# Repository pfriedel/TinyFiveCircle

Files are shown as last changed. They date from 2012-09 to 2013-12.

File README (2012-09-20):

Requirements:

1) 5 RGB LEDs - I'm using common anode, but it'll work with common cathode.
   Just differently.  You'll have to map out the pins and colors differently.

2) ATtiny85

3) PCB from OSHpark.  I'm working on a kit.

BOM: (prices are volatile)

1x MCU: http://www.dipmicro.com/store/ATTINY85-20PU ($1.56)
4x 10mm RGB Common Anode LEDs: http://www.dipmicro.com/store/LED10AD ($2)
1x 3xAA Battery holder: http://www.dipmicro.com/store/BH2465 ($3.21)
4x resistors - mine are 1ohm! But 47 is probably more reasonable

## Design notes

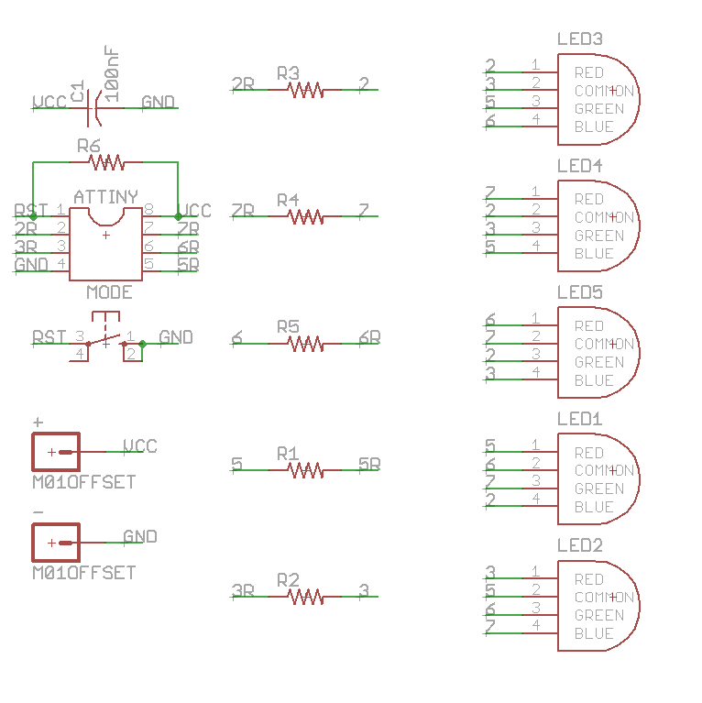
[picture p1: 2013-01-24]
Boards/Tiny RGB Schematic.png

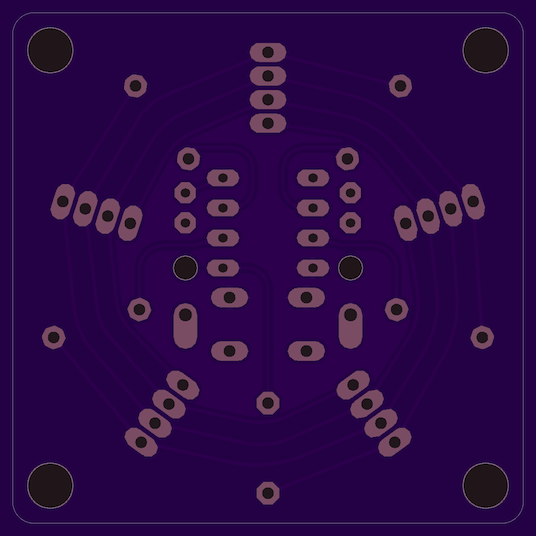
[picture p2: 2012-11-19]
Boards/board_bottom.png

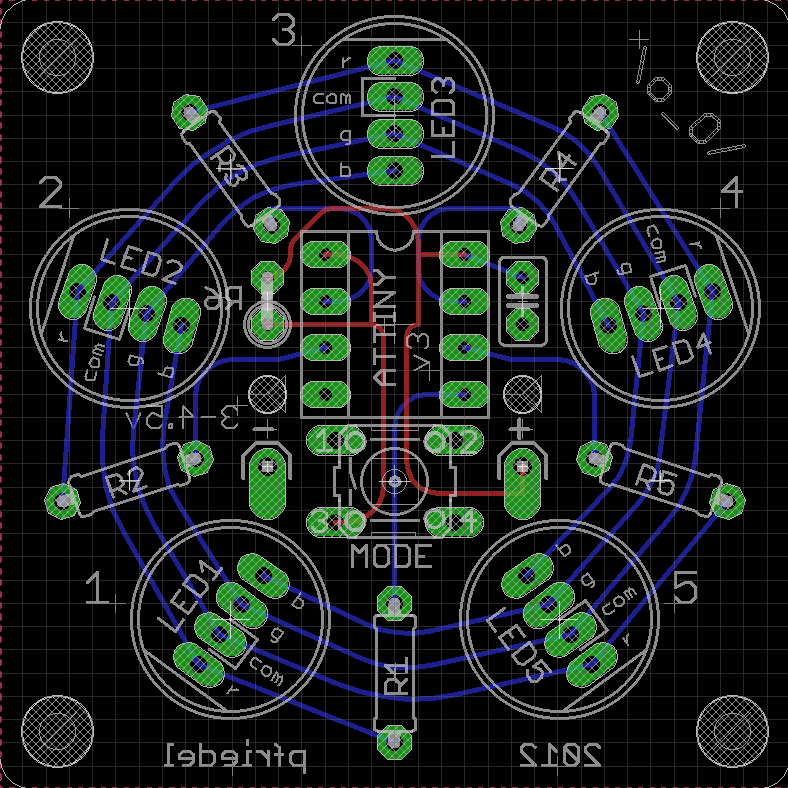
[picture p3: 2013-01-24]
Boards/Tiny RGB Board.png

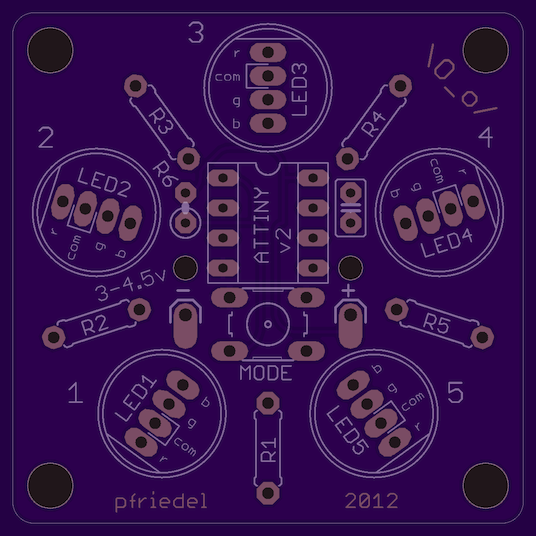
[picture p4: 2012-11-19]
Boards/board_top.png

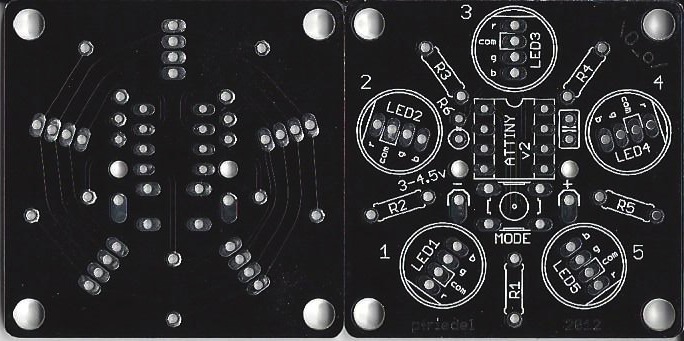
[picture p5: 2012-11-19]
Boards/iTead Boards.jpg

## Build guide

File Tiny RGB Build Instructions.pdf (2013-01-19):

# Tiny RGB Build Instructions

## PARTS LIST:

Quantity | Name | Location | Description
1 | Circuit Board | -
5 | 10mm Common Anode RGB LEDs | LED1-LED5
5 | 68 Ω resistors | R1-R5 | blue - gray - black - silver - brown
1 | 10k Ω resistor | R6 | brown - black - black - red - brown
1 | 100 nF capacitor | - | Labeled “104”
1 | 8 pin socket | ATTINY
1 | ATtiny85 | ATTINY | ATTINY85-20PU
1 | Tact Switch | MODE | 6 x 6 x 15 mm
1 | 3 x AA Battery Box

## BUILD INSTRUCTIONS:

Please familiarize yourself with all of the instructions before you begin as there are some helpful hints scattered throughout the project that help with later steps.

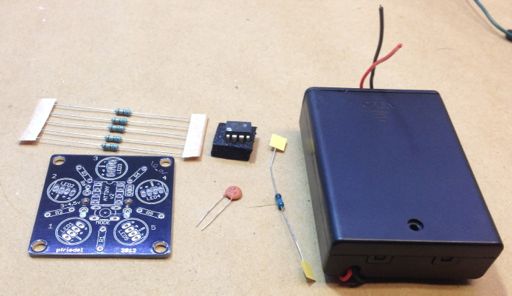
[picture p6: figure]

1. The contents of the kit - the circuit board, five 68 Ω resistors on a strip, a solitary 10k Ω resistor, the 100 nF capacitor, the microcontroller in a piece of foam and the battery box. The LEDs, socket, and tact switch are all inside the battery compartment. If you can’t find a part, open up the battery box and inspect it carefully - I may have changed how I pack everything, but it will all be in the static bag.

There might be slight cosmetic differences to the board between production runs, but the part locations should stay consistent. The general philosophy of what order the parts are installed generally goes from shortest to tallest. Since the resistors are the shorted items in the kit, let’s start with them!

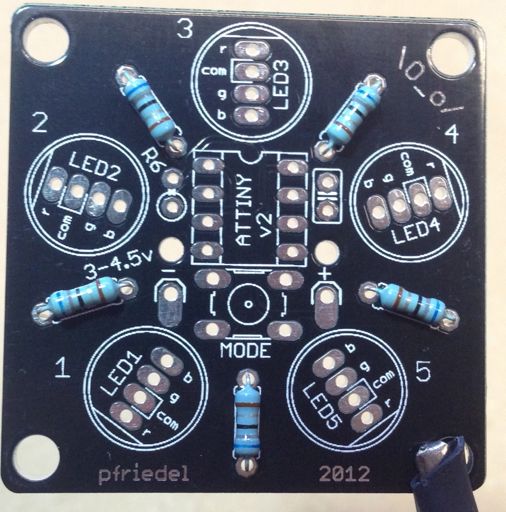
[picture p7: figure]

2. First insert all five 68 Ω resistors in positions R1 through R5 as shown. Flip the circuit board over and solder them and clip the excess leads once they’re soldered. Resistors don’t have any polarity, so you can insert them in either direction. You can solder them one by one if you’re more comfortable soldering them that way.

The 68 Ω resistor looks like this:

These resistors act as current limiters for the LEDs. If you swap them for ones with smaller values, the first thing that tends to happen is the microcontroller goes into a constant state of reset and nothing happens or the system flickers and restarts continually. If you let it happen for long enough, you could also burn out the microcontroller or possibly damage an LED. This is voltage sensitive: If you intend on using this from a 3v source, you can get away with smaller resistors - 27 Ω is comfortable for 3v for example. 68 Ω is plenty for 4.5v and what is included in the kit.

2012-nov-25 / 1

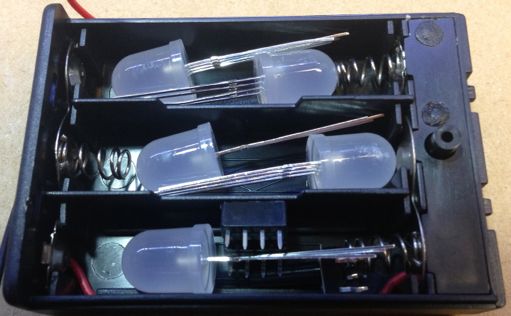
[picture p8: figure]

3. Open the battery box and remove the parts. You’ll need the 8 pin socket for the next step, so retrieve it and set the other parts aside.

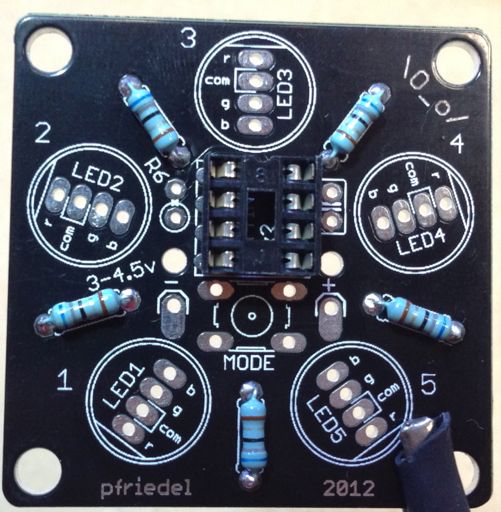
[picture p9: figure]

4. Insert the 8 pin socket in the spot labeled ATTINY. Make sure the little cutout in the socket matches the cutout on the silkscreen

Helpful hint: While it isn’t strictly necessary, I find that it helps to fold over the socket legs on the other side of the board. Since the power lines run right along here, it helps to reduce the number of points that can stab through the power leads.

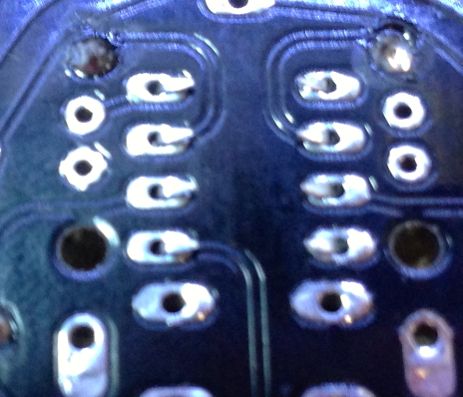
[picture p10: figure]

Solder the socket in place. Since the leads are so short, you usually don’t need to trim them, and if you fold them over you definitely won’t be able to.

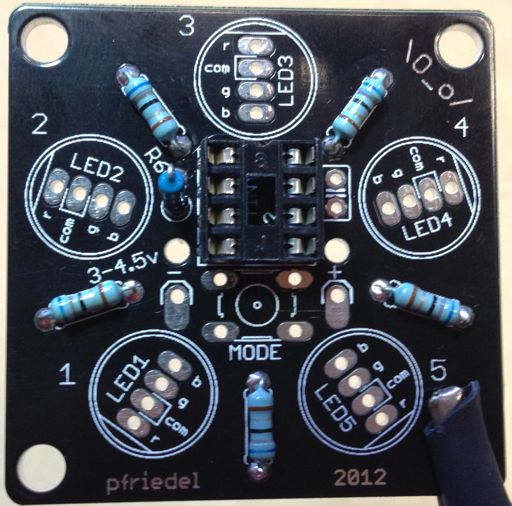
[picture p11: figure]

5. Insert the remaining 10k Ω resistor in the spot marked R6. You’ll have to fold the resistor in half like so to get it into the holes.

Once you have it in place, solder it and clip the leads again. It doesn’t matter if you fit the resistor body up against the circle on the silkscreen, that’s merely an aesthetic choice.

This resistor acts as a pull-up for the reset pin and helps prevent electrical noise from generating an unintended reset.

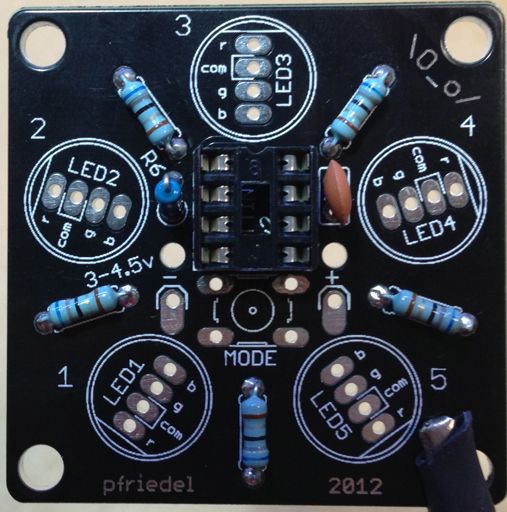
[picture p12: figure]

6. Insert the 100 nF capacitor marked “104” in the holes on the opposite side of the socket. Solder it into place and clip the leads. Ceramic capacitors like this aren’t polarized, so it doesn’t matter which lead goes into which hole. This capacitor acts as a noise filter from the high frequency noise that the circuit can generate. Each LED will get turned on and off at a high rate, and every time the LED is turned on and off, the current draw from the battery is affected - this capacitor acts as a buffer for those changes.

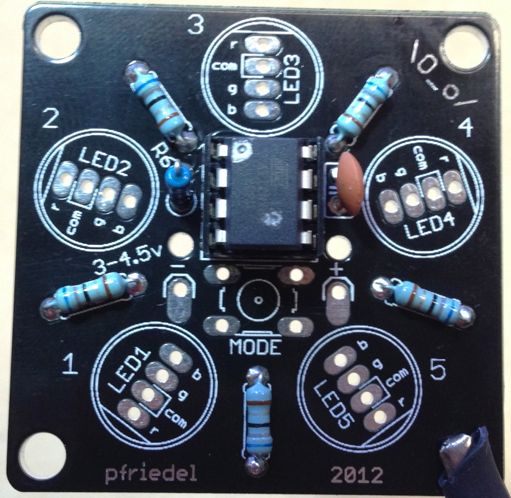
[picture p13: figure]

7. Now you should insert the ATtiny85 microcontroller in the socket. I’ve put a little silver paint dot indicating which pin is pin 1 on the microcontroller. This should be on the same side as the cutout in the socket. If you inserted the socket backwards, don’t worry, just make sure that the microcontroller is oriented correctly. When you receive the microcontroller, its legs will be splayed a bit. In order to get the chip in the socket, you will need to bend the legs in so they are parallel. With 8 pin chips such as the ATtiny85, you can usually just gently squeeze them between your fingers, but if you aren’t comfortable doing that, you can also use your bench top to flatten them like so:

Just be gentle and don’t crush the chip - it doesn’t take a lot of force to bend the legs.

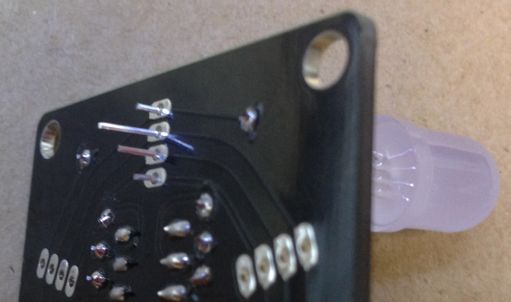
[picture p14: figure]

8. Now you will need to insert and solder the LEDs. The LEDs are polarized, which means that it’s important you get the right legs into the right holes. You’ll notice that the holes are all marked “r”, “com”, “g” and “b” - those line up with the legs of the LEDs. Insert the longest leg into the “com” hole and the next longest leg into the “g” hole. Feed the next two legs into the “r” and “b” holes, then gently push the LED into place. As you start, the legs will look like the picture to the left.

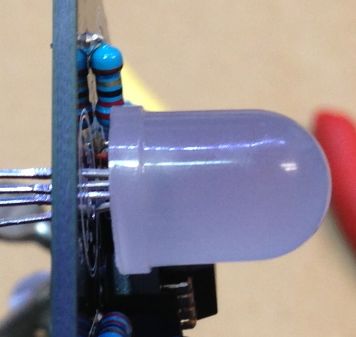
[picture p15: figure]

If you look carefully at the legs you’ll see a section where they’re slightly flatter than the rest of the leg. Your goal will be to get the LED seated far enough that the shoulder of those flat spots is just through the circuit board. The LED will not be seated flat to the board - it will look like the picture to the left. Solder one of the legs and then look at the LED carefully and try to make it as square to the board as you can. Once you’re happy with the LED’s position, you can solder in the other 3 legs. Be gentle with the LEDs during this step - if you push too hard, you could rip the leg right out of the LED which would ruin the LED. Once you’ve soldered all 20 legs, clip the legs flush to the board.

Helpful hints:
- You might want to skip ahead and solder the pushbutton in after you solder in LEDs 2, 3 and 4 and before you solder in LEDs 1 and 5, depending on how small your fingertips are. It can be a tight fit to get it in after all the LEDs are in place.
- If you don’t have a helping hand tool, you can balance the unpopulated half of the board on the back of the battery box for the first few LEDs. By time you’re soldering the 3rd and later LEDs, the board self stabilizes fairly well on the tops of the LEDs.

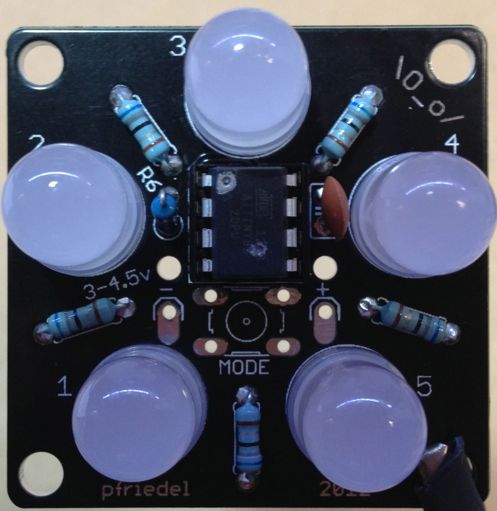
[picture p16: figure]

9. Once you’re done with the LEDs, your board should look like this. Insert the tact switch in the board - it’s slightly rectangular, so it should only want to snap in to the board one way. If in doubt, the silver legs come off of the left and right side of the switch. If you get this rotated 90 degrees off, the reset button will be constantly depressed, and the microcontroller won’t start to run the program.

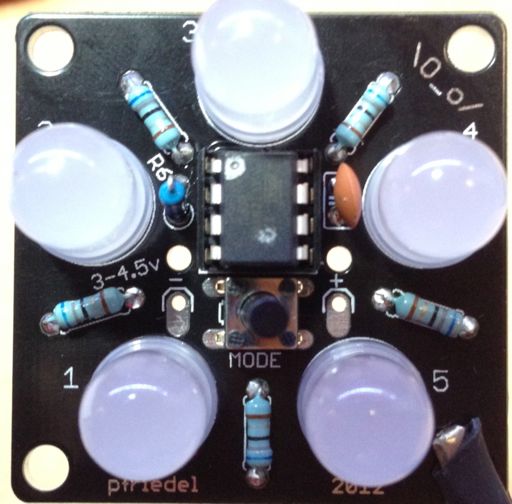
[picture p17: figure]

10. At this point, the controller board is done. If you want to power it from a USB cable, you should be able to power it directly to the negative and positive terminals on the board. If you want to power it from the included battery box, follow along on the next page.

Helpful hint:
I highly recommend temporarily testing the circuit with the battery box before you solder it in to place to ensure that the kit is working properly. Once you solder the board to the box, repair and rework is more difficult. Simply connect the negative (black) lead from the battery box to the negative (-) pad on the board, and the positive (red) lead from the battery box to the positive (+) pad on the board. Be careful to get the power leads connected the right way around - the microcontroller will eventually fail if it’s hooked up backwards.

If any of the LEDs fail to light up or if any of the LEDs start up and glow white or any other solid color without changing like their neighbors, skip forward to the troubleshooting section.

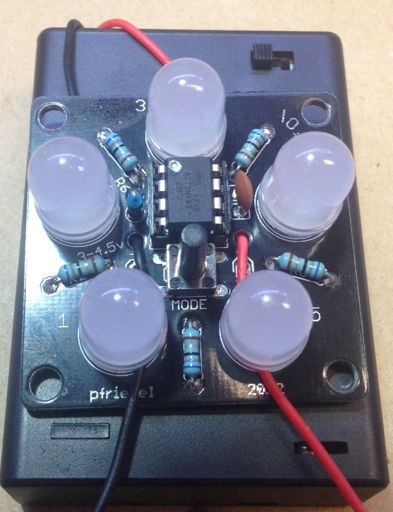
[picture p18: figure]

11. Thread the black negative lead up from the back of the board to the front of the board and do the same for the red positive lead. Adjust the length of the wires so there isn’t too much extra loose wire. At this point I usually try to make a mark on the wire where it passes over the hole and where it passes over the lower bound of the solder pad. Then I unthread the wire and trim it to length with a wire cutter and strip back the insulation and tin the exposed wire with a little bit of solder so the thin wires inside the red and black wires are coated in a small layer of solder.

Make sure the battery box is empty or the power switch is turned off at this point -it’s easy to short out power with solder while making the next couple of connections, and that could damage the microcontroller or LEDs.

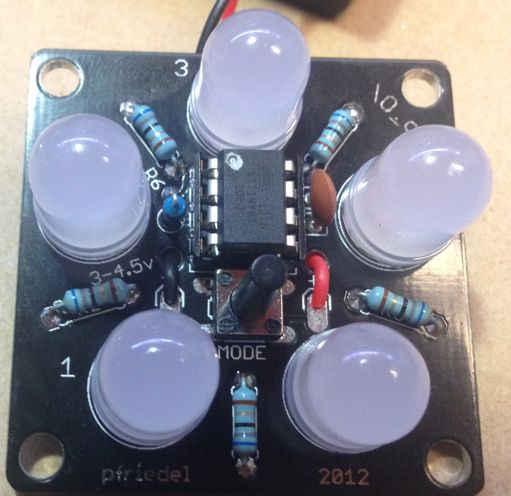
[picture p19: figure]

12. Once you have trimmed and tinned the battery wires, thread them up from the back of the board again and loop them over to the solder pads as shown on the left.

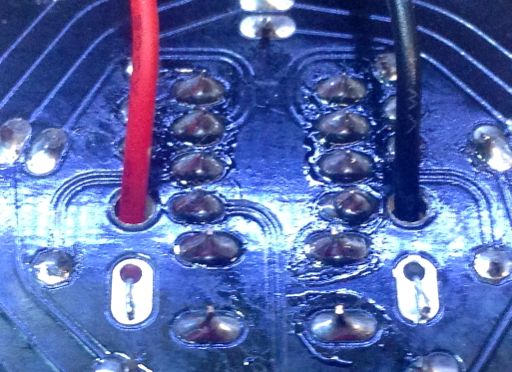
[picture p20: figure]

The back of the board should look like this. Solder the wires into place and tighten the excess from the front. Attach the board to the battery box with double sided sticky tape or hot glue. The board is now finished. Insert batteries and flip the power switch and it should start from mode 1.

## TROUBLESHOOTING:

The first mode should never show a fully white color. If you see white, there’s a short somewhere on the board. If you have a multimeter, you can use the diagram to the left to determine which points should have continuity and which ones shouldn’t, which will help you narrow down the problem LED to one of three. (e.g. if there’s a short between pins 7 and 2, it could be in any of the LEDs in the 10 o’clock position, the 7 o’clock position or the 5 o’clock position.)

If you’re feeling especially cautious you can confirm there aren’t any short circuits between any two pins on any single LED before moving on to the next one while you’re soldering them, which greatly narrows down the possible faulty components to the one you just added.

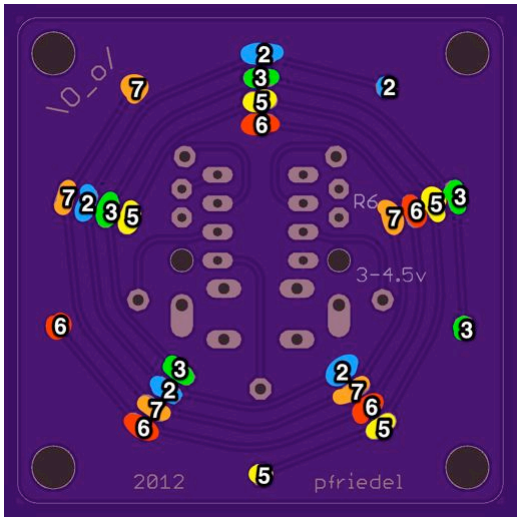
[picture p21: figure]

## DISPLAY MODES:

The board will change display modes every time you hit the MODE button. The board will tell you which mode you are entering by lighting up the LED associated with that mode which is next to a number on the board. 1-5 are indicated by red LEDs while 6-10 are indicated by green LEDs.

1. (Red 1) A slow walk through all the hues of the color spectrum.
2. (Red 2) A faster walk through the color hues.
3. (Red 3) Even faster than #2.
4. (Red 4) A slow progression with every color mapped one to one to LEDs. While modes 1-3 work with a wide virtual LED space, this mode and the next one work only with the physical LEDs.
5. (Red 5) A faster version of #4.
6. (Green 1) Random colors at random positions, changing every second or so.
7. (Green 2) Bouncing up and down in hue saturations, slowly walking through hues.
8. (Green 3) The same as #7, with a faster hue progression.
9. (Green 4) Displays the red, green and blue LEDs directly without mixing. Useful for spotting a bad LED.
10. (Green 5) Randomly selects any of the prior 9 modes and displays it for 5 minutes before selecting the next mode.

The system will automatically enter a low power sleep mode after 4 hours of modes 1-9, but mode 10 will run until the batteries run down. If you hit the MODE button while the system is in the low power mode, it will wake up and resume the previously running mode for another 4 hours. If you hit the MODE button again while it is still indicating which mode it is about to enter, it will advance to the next mode.

The low power mode is drawing just under 2 µA, so the power switch isn’t strictly necessary - 2 µA is on the order of the battery’s self discharge rate.

In normal use the board draws about 20 mA - the expected lifespan on standard Alkaline AAs is about a week nonstop or 168 hours. As the batteries die, the LEDs will slowly start to fade and each color will start to fail one by one. If you only use the 4 hour timed mode once a day, each set of batteries will last over a month given good alkaline cells.

## SOURCE CODE:

The software repository for this project is at https://github.com/pfriedel/TinyFiveCircle

Any questions? Mail me - pfriedel@compulsive.net.

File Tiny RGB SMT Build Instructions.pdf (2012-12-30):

# Tiny RGB SMT Build Instructions

## PARTS LIST:

Quantity | Name | Location | Description
1 | Circuit Board | -
5 | 5050 RGB LEDs | LED1-LED5
5 | 68 Ω resistors | - | 680
1 | 10k Ω resistor | - | 103
1 | 100 nF capacitor | - | 104
1 | ATtiny85 | ATTINY | ATTINY85-20SU
1 | Tact Switch | MODE | 6 x 3 x 4.3 mm
1 | 3 x AA Battery Box

## BUILD INSTRUCTIONS:

Since this is a slightly advanced build, I’m not going to walk through each step of the process as much as I do in my beginner kits. The instructions for this kit are intended to help guide the build order and any tips I’ve discovered while building the prototype boards.

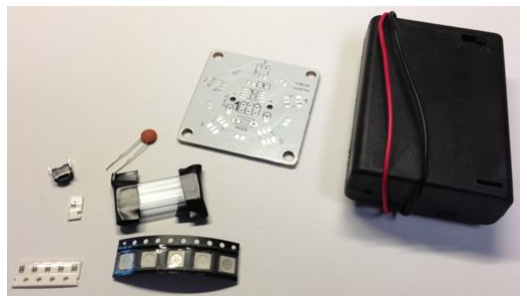
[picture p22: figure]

1.The contents of the kit - the circuit board, five 68 ohm resistors on a strip, a solitary 10k resistor, the 100 nF capacitor, the microcontroller in a segment of packing tube and the battery box. Everything other than the PCB is inside the battery compartment, so open it up and carefully extract all the parts.

2. A quick overview of the board as it doesn’t have much in the way of part labeling on the front:
- The red arrows point to the 68 Ω resistor pads. The 68 Ω resistors are marked “680” on their faces.
- The blue arrow points to the 10k Ω resistor pad. The 10k Ω resistor is marked “103”.
- The green arrow points towards the solitary capacitor pad. If you have a 100nF SMD capacitor, you could use the holes for SMD pads, otherwise use the through hole capacitor included with the kit.
- The black arrow points to the microcontroller’s first pin. There’s a small black dot on the board to indicate the orientation of the microcontroller. If you solder the microcontroller onto the board backwards, it won’t work, and it’s a pain to get off the board. Always double check the orientation of polarized parts.
- The orange arrows point to pin 1 of the 5050 RGB LEDs.

The 68 Ω resistors act as current limiters for the LEDs. If you swap them for ones with smaller values, the first thing that tends to happen is the microcontroller goes into a constant state of reset. If you let it happen for long enough, you could also burn out the microcontroller or possibly damage an LED. As this is voltage sensitive, if you intend on using this from a 3v source, you can get away with smaller resistors -27 Ω is comfortable for 3v for example. 68 Ω is plenty for 4.5v. The 10k resistor pulls

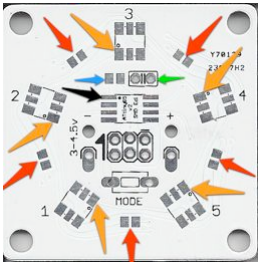
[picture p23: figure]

up the microcontroller’s reset pin and helps prevent erratic behavior. The capacitor helps filter power coming from the batteries, but I haven’t ever had problems running from batteries without a filtering capacitor, so if you wish to leave it off, the circuit still works without it.

2012-dec-30 / 1

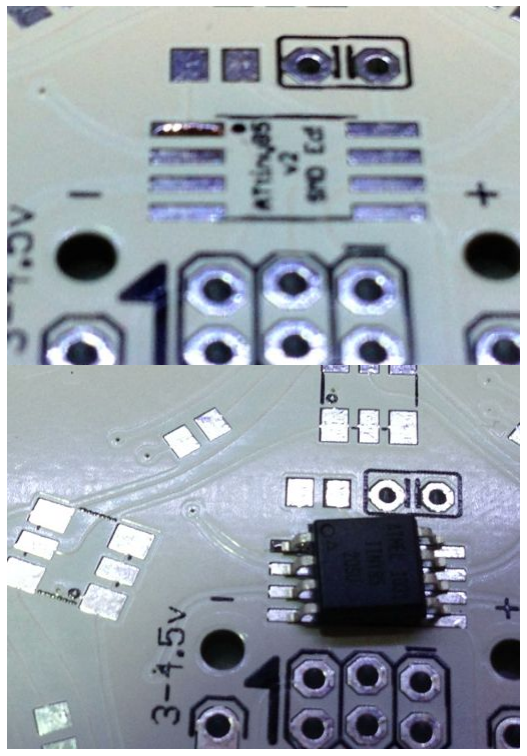
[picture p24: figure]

3. Open the battery box and remove the parts. Be careful to not lose the 10k resistor since it’s so small. I always start with the microcontroller, since the microcontroller’s pads are large enough to get me prepared for surface mount parts. Add a little bit of solder to the first pin on the board and use that to reflow the chip into place. If you need a guide to reflow soldering, I can’t recommend Dave Jones’ guide highly enough:

http://youtu.be/b9FC9fAlfQE

And Jeremy’s guide is also helpful:

http://thecustomgeek.com/2012/06/14/smd-soldering-you-can-do-it/

Either way it boils down to adding a bit of solder to a pin on the board and using that to reflow solder onto the component. The biggest problems are solder control and flux management. You want the finest solder you can find - when I was trying it with 0.032” solder, even the lightest dab of solder added far too much. It’s much easier to control how much solder you add with finer solders - I ended up with 0.015” silver solder because the 0.032” was too hard to manage, and it worked out fine. Solder all 8 legs of the microcontroller before moving on to the next step. Check it for shorts and poorly soldered joints with magnification. I do all of my work with a head visor that doesn’t really provide that much magnification - I think it’s only good for about 3x, but it’s enough to see the components up close.

4. Add flux to the board and start soldering the LEDs into place. The LEDs have a little notch in them to indicate pin 1 as shown in this picture:

The board indicates pin 1 with a little black dot. Make absolutely certain that the LED is in the right orientation before you start to solder it into place - the leads on the LEDs make removing them a difficult proposition once they’re all soldered into place.

I found it easiest to solder them into place by starting with pins 2 and 5, the two skinnier pads in the middle. That way, if the LED ends up slightly off center, the opposite pad won’t have enough available pad to start to solder to, and it’s easier to reheat the opposite pad to assist in moving the LED. Flood pad 2, tack the LED into place, then snap it into place using your finger and the iron. The clear part of the

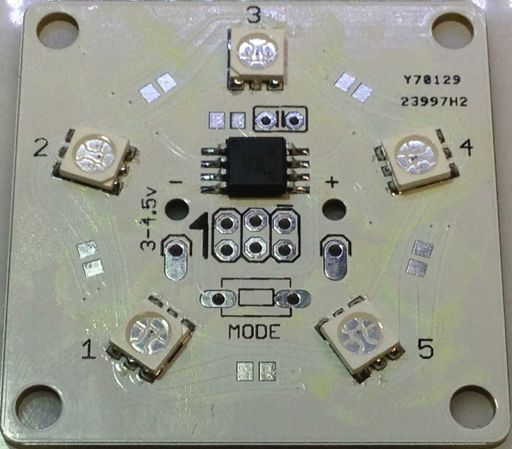
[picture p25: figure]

LED scratches very easily - I never felt comfortable pressing it into place with the tweezers. Make sure you have the LED centered and rotated properly before proceeding to pin 5. If you can’t get pin 5 to flow, try to move the LED a little bit by reflowing pin 2. The LED can take a surprising amount of heat, but be careful just the same. I haven’t cooked off any, but the bond wire is very fine and it’s connected directly to the lead so it wouldn’t take much. Once pins 2 and 5 are soldered, proceed to pins 1, 3, 4 and 6. Once you have one LED on the board, you can do the other 4 the same way.

I did the work with a reasonably broad chisel tip as well as a fine tip and honestly the fine tip wasn’t any easier than the broad tip. The fine point tip was absolutely useless on the through hole components, though.

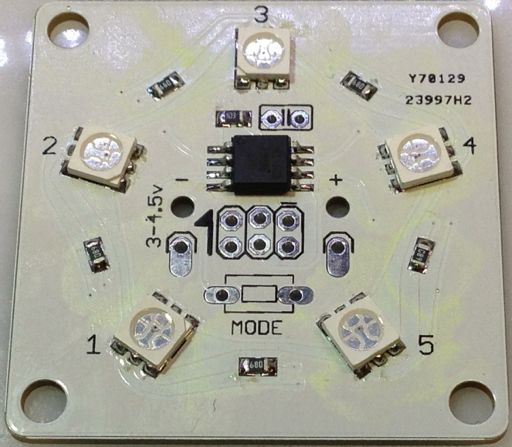
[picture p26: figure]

5. Solder on the resistors. After the LEDs, they’re pretty simple. Flood one pad, tack it into place, then press it down onto the board before soldering the other pad.

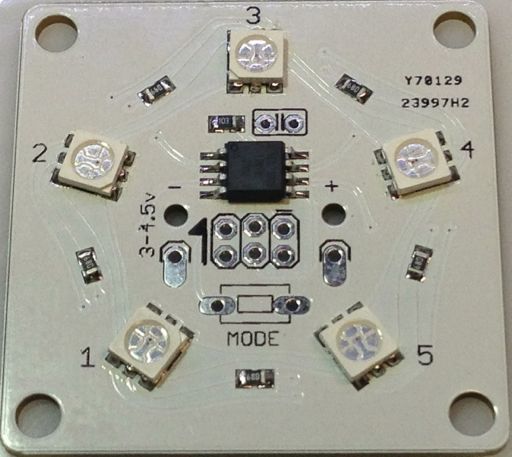
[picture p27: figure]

6. Clean the accumulated flux off of your board before soldering on the switch. Use whatever your flux requires - mine cleans up nicely with rubbing alcohol, yours might need something different.

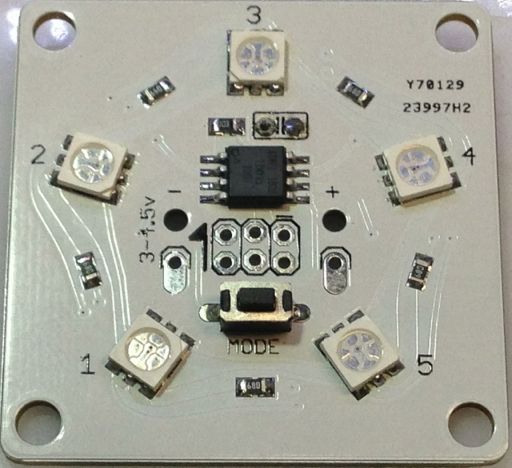
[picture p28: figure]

7. Solder the Mode switch into position. It isn’t polarized, so it doesn’t matter which way you solder it into place.

At this point, the board is done. If you want to power it from a USB cable, you should be able to power it directly to the negative and positive terminals on the board. If you want to power it from the included battery box, follow along on the next page.

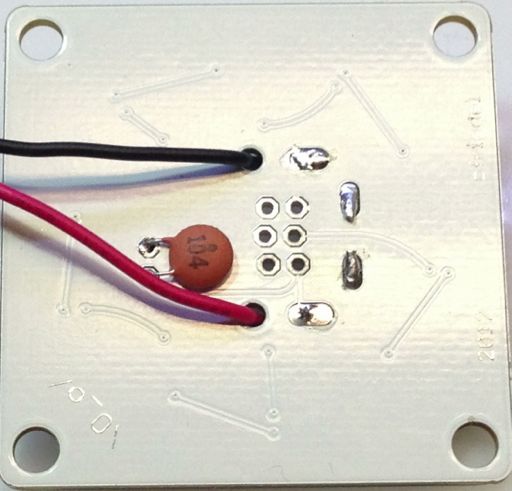
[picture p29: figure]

8. Thread the black negative lead up from the back of the board to the front of the board and do the same for the red positive lead. Adjust the length of the wires so there isn’t too much extra loose wire. At this point I usually try to make a mark on the wire where it passes over the hole and where it passes over the lower bound of the solder pad. Then I unthread the wire and trim it to length with a wire cutter and strip back the insulation and tin the exposed wire.

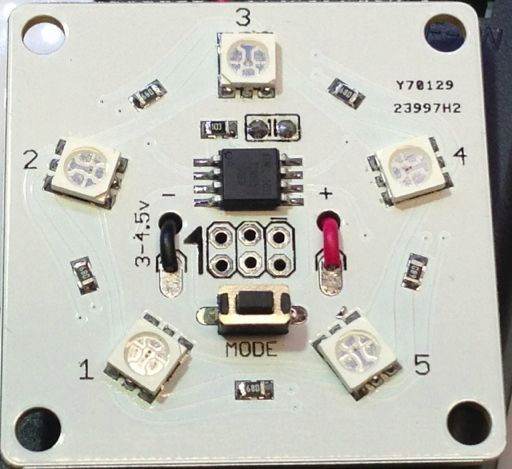
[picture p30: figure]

9.Once you have trimmed and tinned the battery wires, thread them up from the back of the board again and loop them over to the solder pads as shown on the left.

Attach the board to the battery box with double sided sticky tape or hot glue. The board is now finished. Insert batteries and flip the power switch and it should start from mode 1.

## TROUBLESHOOTING:

The resistors aren’t labeled on the board, but they’re all counter-clockwise from their associated LED. So R1 is below the Mode switch, R2 is clockwise from that, R3 is clockwise from that, etc. To test LED function, 4.5v through more than 130 Ω resistance should light up the LEDs listed in the table to the right. Unlisted connections might produce some light (sometimes across 2 LEDs, even), but those aren’t ever called out in the code, so don’t worry about them if they light up.

The LEDs are arranged such that pins 1 and 6 are blue, pins 2 and 5 are red and 3 and 4 are green.

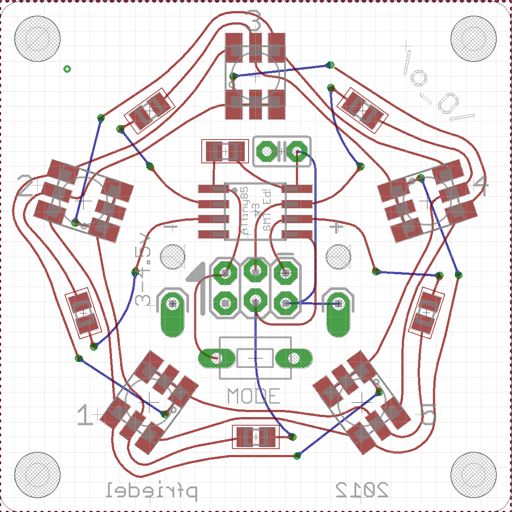
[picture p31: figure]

## DISPLAY MODES:

Each time you hit the MODE button, the board will advance modes. The board will tell you which mode you are entering by lighting up the LED associated with that mode which is next to a number on the board. 1-5 are indicated by red LEDs while 6-10 are indicated by green LEDs.

1. A slow walk through all the hues of the color spectrum.
2. A faster walk through the color hues.
3. Even faster than #2.
4. A slow progression with every color mapped one to one to LEDs. While modes 1-3 work with a wide virtual LED space, this mode and the next one work only with the physical LEDs.
5. A faster version of #4.
6. Random colors at random positions, changing every second or so.
7. Bouncing up and down in hue saturations, slowly walking through hues.
8. The same as #7, with a faster hue progression.
9. Displays the red, green and blue LEDs directly without mixing. Useful for spotting a bad LED.
10. Randomly selects any of the prior 9 modes and displays it for 5 minutes before
selecting the next mode.

The system will automatically enter a low power sleep mode after 4 hours of modes 1-9, but mode 10 will run until the batteries run down. If you hit the MODE button, the system will wake up and resume the running the previous mode for another 4 hours. If you hit the MODE button again while it is still indicating which mode it is about to enter, it will advance to the next mode.

The low power mode is drawing just under 2 µA, so the power switch isn’t strictly necessary - 2 µA is on the order of the battery’s self discharge rate.

In normal use the board draws about 20 mA - the expected lifespan is about a week nonstop - 168 hours. As the batteries die, the LEDs will slowly start to fade and each color will start to fail one by one. If you only use the 4 hour timed mode once a day, each set of batteries will last over a month given good alkaline cells.

Negative | Positive | LED / Color
1 | 2 | 3 / Green
1 | 3 | 4 / Blue
1 | 5 | 1 / Red
2 | 3 | 4 / Green
2 | 4 | 5 / Blue
2 | 1 | 2 / Red
3 | 4 | 5 / Green
3 | 5 | 1 / Blue
3 | 2 | 3 / Red
4 | 5 | 1 / Green
4 | 1 | 2 / Blue
4 | 3 | 4 / Red
5 | 1 | 2 / Green
5 | 2 | 3 / Blue
5 | 4 | 5 / Red

## SOURCE CODE:

The software repository for this project is at https://github.com/pfriedel/TinyFiveCircle

Any questions? Mail me - pfriedel@compulsive.net.

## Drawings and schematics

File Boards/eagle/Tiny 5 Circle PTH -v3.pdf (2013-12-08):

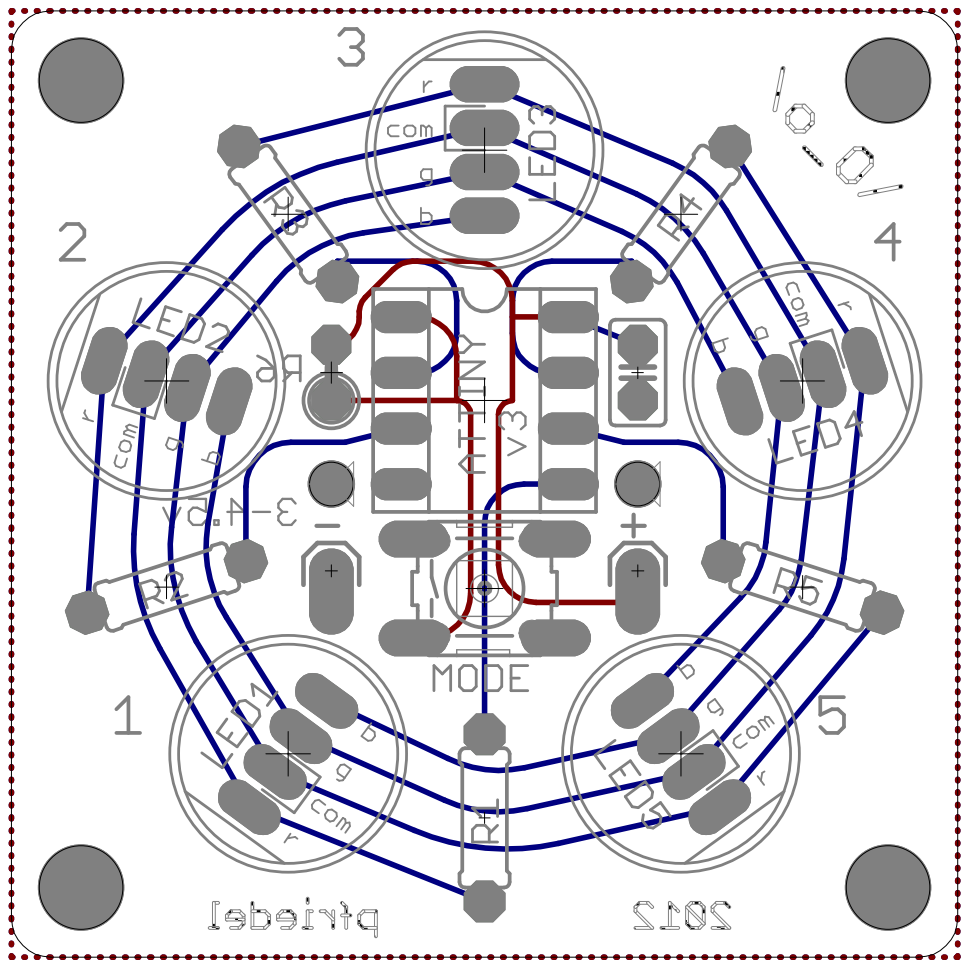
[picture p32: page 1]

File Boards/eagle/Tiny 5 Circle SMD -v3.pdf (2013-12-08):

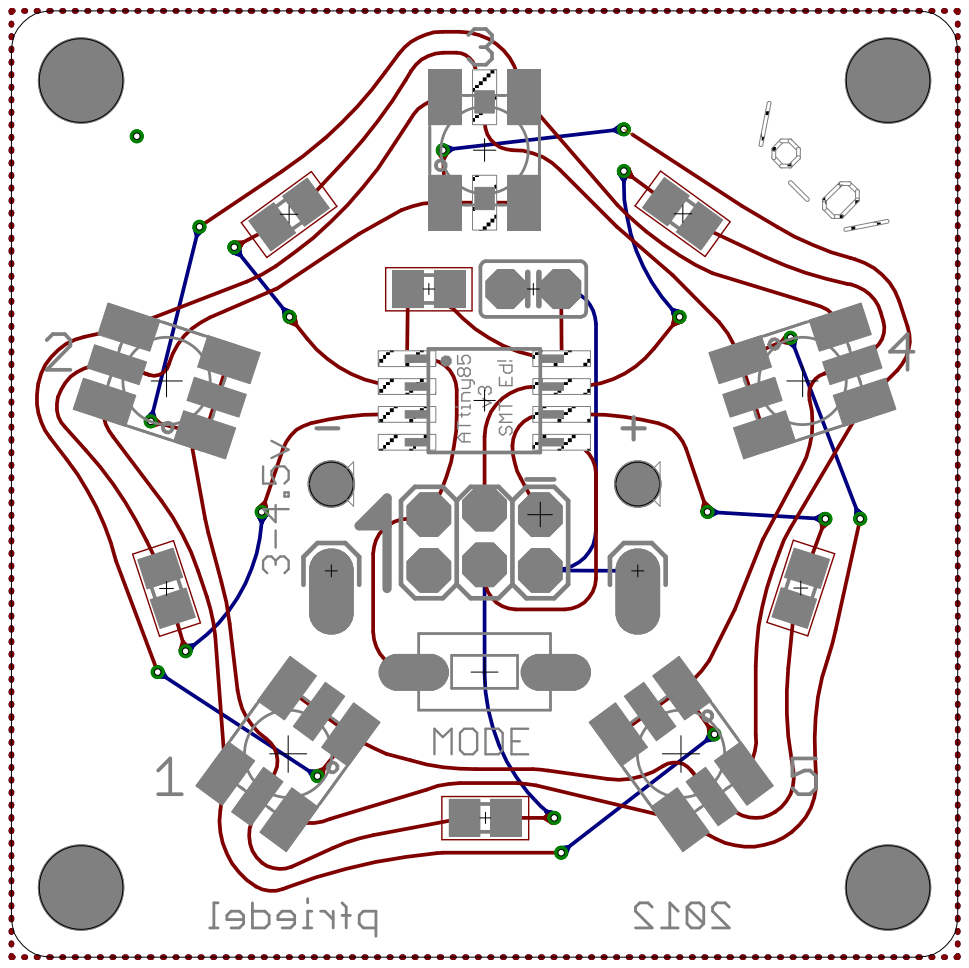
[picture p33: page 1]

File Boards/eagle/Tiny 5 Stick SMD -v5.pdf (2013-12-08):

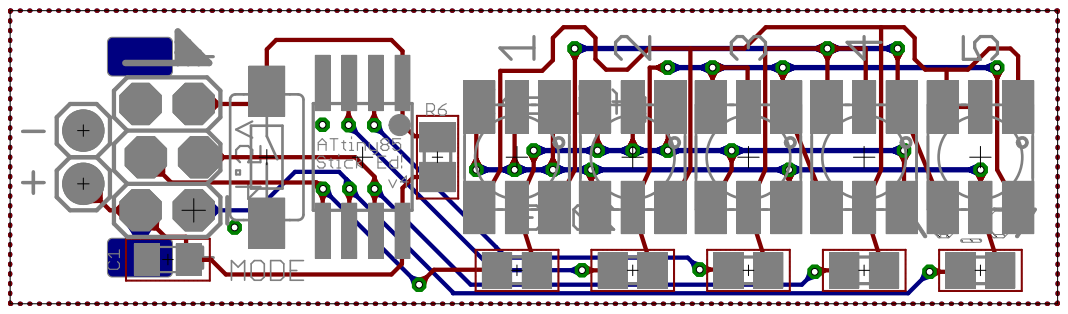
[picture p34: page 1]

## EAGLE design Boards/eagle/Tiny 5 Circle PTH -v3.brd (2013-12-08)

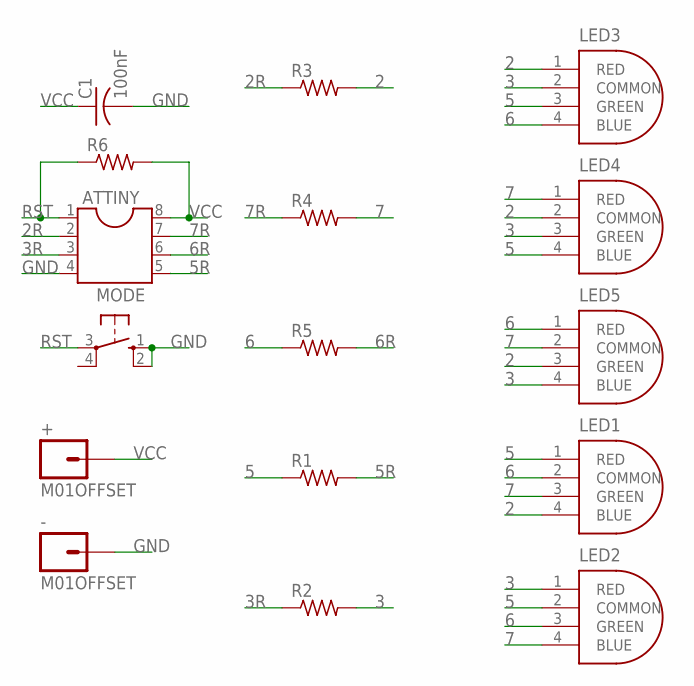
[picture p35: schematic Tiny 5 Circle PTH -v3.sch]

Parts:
+: M01OFFSET; 1X01_OFFSET
-: M01OFFSET; 1X01_OFFSET
ATTINY: DIL8S; SOCKET-08
C1: 100nF; C025-025X050
LED1, LED2, LED3, LED4, LED5: 10MM-RGB-LEDACTIVELYUSED; 10MM-RGB-LED-IN-USE
MODE: 10-XX; B3F-10XX
R1, R2, R3, R4, R5: R-US_0207/7; 0207/7
R6: R-US_0207/2V; 0207/2V

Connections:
2: LED1.4 (BLUE), LED3.1 (RED), LED4.2 (COMMON), LED5.3 (GREEN), R3.2
2R: ATTINY.2, R3.1
3: LED2.1 (RED), LED3.2 (COMMON), LED4.3 (GREEN), LED5.4 (BLUE), R2.2
3R: ATTINY.3, R2.1
5: LED1.1 (RED), LED2.2 (COMMON), LED3.3 (GREEN), LED4.4 (BLUE), R1.1
5R: ATTINY.5, R1.2
6: LED1.2 (COMMON), LED2.3 (GREEN), LED3.4 (BLUE), LED5.1 (RED), R5.1
6R: ATTINY.6, R5.2
7: LED1.3 (GREEN), LED2.4 (BLUE), LED4.1 (RED), LED5.2 (COMMON), R4.2
7R: ATTINY.7, R4.1
GND: -.1, ATTINY.4, C1.2, MODE.1 (S), MODE.2 (S1)
RST: ATTINY.1, MODE.3, R6.1
VCC: +.1, ATTINY.8, C1.1, R6.2

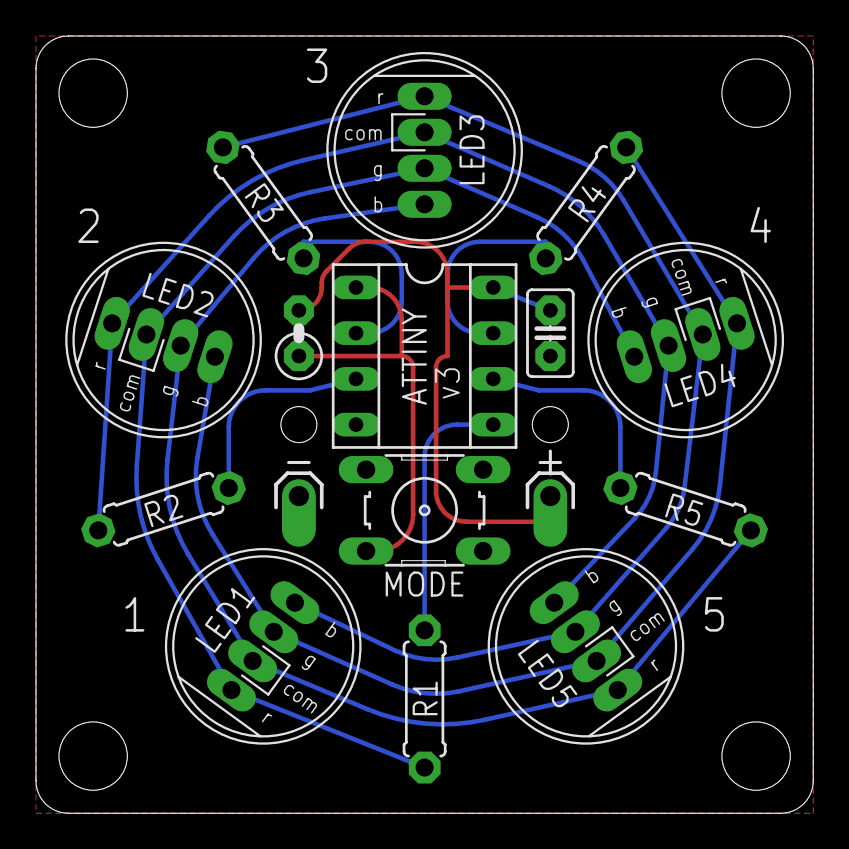
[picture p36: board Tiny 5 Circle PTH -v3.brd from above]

Board: 2 copper layers, 43.2 x 43.2 mm, 16 parts (0 on the bottom side), 13 nets.

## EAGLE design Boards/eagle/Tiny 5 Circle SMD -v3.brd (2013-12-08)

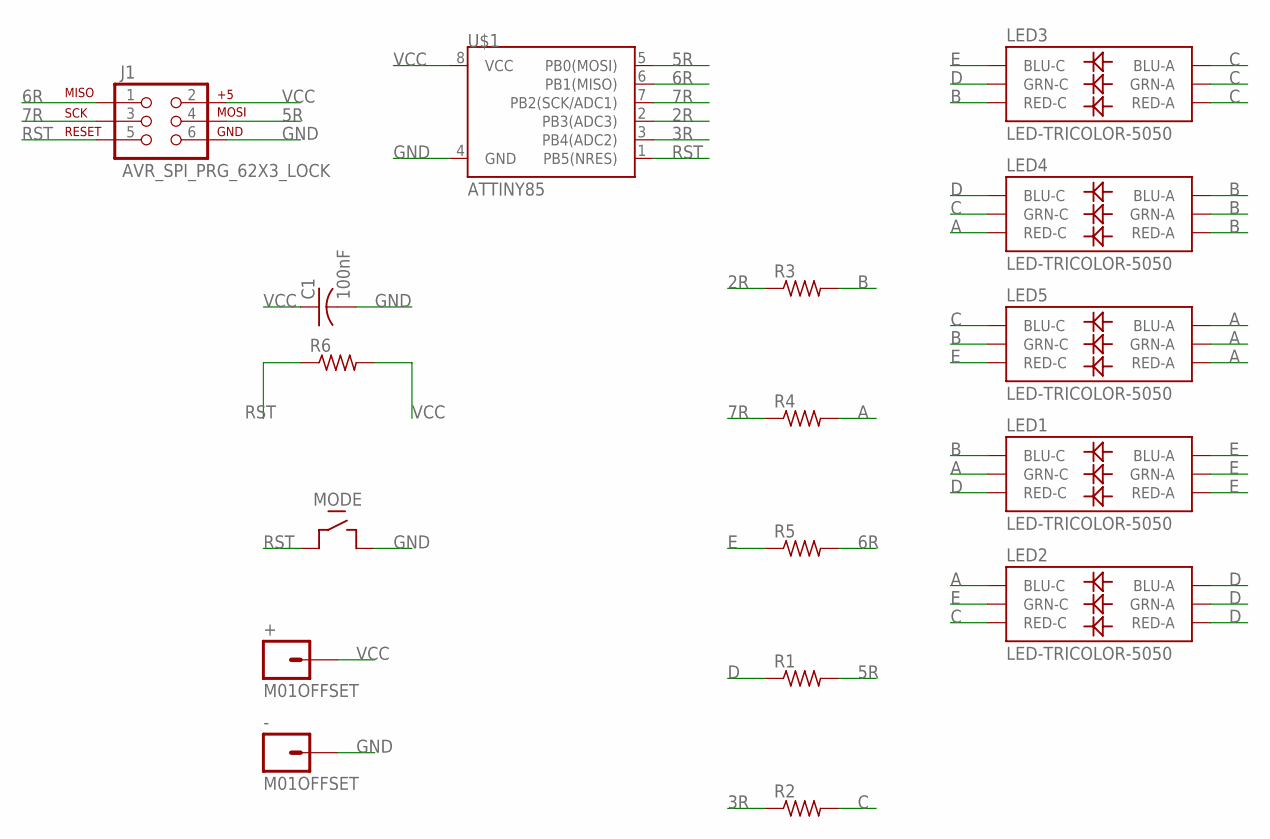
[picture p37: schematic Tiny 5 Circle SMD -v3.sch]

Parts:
+: M01OFFSET; 1X01_OFFSET
-: M01OFFSET; 1X01_OFFSET
C1: 100nF; C025-025X050
J1: AVR_SPI_PRG_62X3_LOCK; 2X3_LOCK
LED1, LED2, LED3, LED4, LED5: LED-TRICOLOR-5050
MODE: 3X6MM_SWITCH; 6X3MM-TACT
R1, R2, R3, R4, R5, R6: R-US_M0805; M0805
U$1: ATTINY85; SO08-EIAJ

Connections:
2R: R3.1, U$1.2 (PB3(ADC3))
3R: R2.1, U$1.3 (PB4(ADC2))
5R: J1.4, R1.2, U$1.5 (PB0(MOSI))
6R: J1.1, R5.2, U$1.6 (PB1(MISO))
7R: J1.3, R4.1, U$1.7 (PB2(SCK/ADC1))
A: LED1.4 (GRN-C), LED2.6 (BLU-C), LED4.5 (RED-C), LED5.1 (BLU-A), LED5.2 (RED-A), LED5.3 (GRN-A), R4.2
B: LED1.6 (BLU-C), LED3.5 (RED-C), LED4.1 (BLU-A), LED4.2 (RED-A), LED4.3 (GRN-A), LED5.4 (GRN-C), R3.2
C: LED2.5 (RED-C), LED3.1 (BLU-A), LED3.2 (RED-A), LED3.3 (GRN-A), LED4.4 (GRN-C), LED5.6 (BLU-C), R2.2
D: LED1.5 (RED-C), LED2.1 (BLU-A), LED2.2 (RED-A), LED2.3 (GRN-A), LED3.4 (GRN-C), LED4.6 (BLU-C), R1.1
E: LED1.1 (BLU-A), LED1.2 (RED-A), LED1.3 (GRN-A), LED2.4 (GRN-C), LED3.6 (BLU-C), LED5.5 (RED-C), R5.1
GND: -.1, C1.2, J1.6, MODE.P$2 (OUT), U$1.4 (GND)
RST: J1.5, MODE.P$1 (IN), R6.1, U$1.1 (PB5(NRES))
VCC: +.1, C1.1, J1.2, R6.2, U$1.8 (VCC)

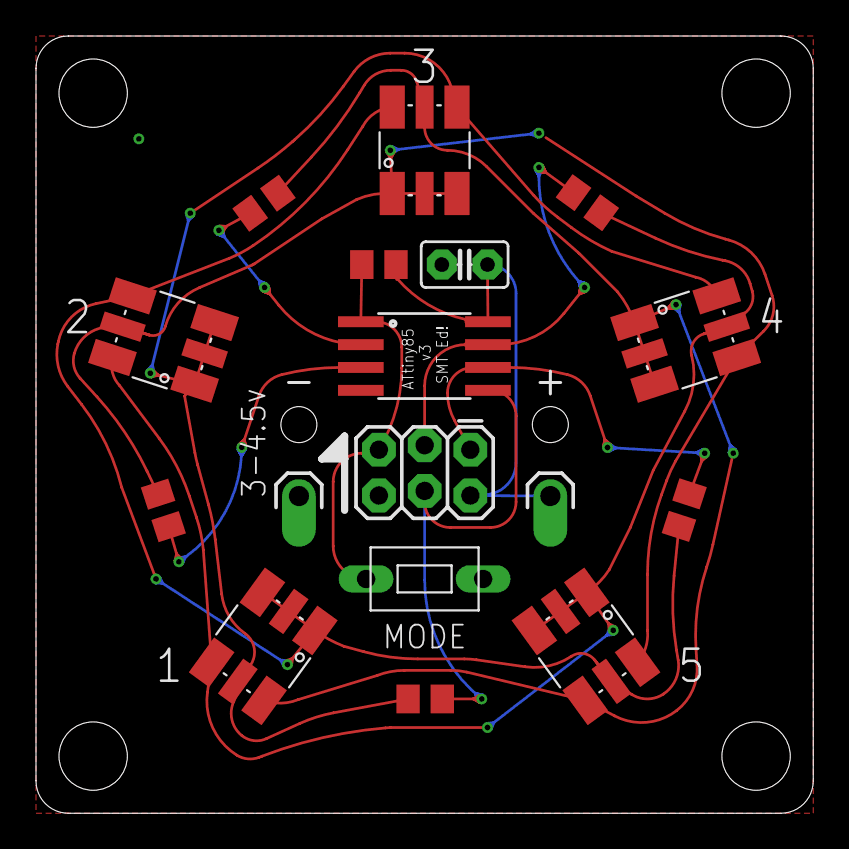
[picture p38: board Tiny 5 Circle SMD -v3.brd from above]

Board: 2 copper layers, 43.2 x 43.2 mm, 17 parts (0 on the bottom side), 13 nets.

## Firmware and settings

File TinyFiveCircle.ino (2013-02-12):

// Tiny85 versioned - ATmega requires these defines to be redone as well as the
// DDRB/PORTB calls later on.

/* commentary: 

Future modes:

1. random color random position - existing mode

2. hue walk at constant brightness - existing mode

3. brightness walk at constant hue - existing mode

4. saturation walk is kind of obnoxious - existing mode

5. "Rain" - start at LED1 with a random color.  Advance color to LED2 and pick a
   new LED1.  Rotate around the ring.

6. non-equidistant hue walks - instead of 0 72 144 216 288 incrementing,
   something like...  0 30 130 230 330 rotating around the ring.  The hue += and
   -= parts might help here?

7. Color morphing: Pick 5 random colors.  Transition from color on LED1 to LED2
   and around the ring.  Could be seen as a random variant of #2.

8. Larson scanner in primaries - Doable with 5 LEDs? (probably, I've seen
   larsons with 2 actively lit LEDs in 4 LEDs before.)

9. Pick a color and sweep brightness around the circle (red! 0-100
   larson-style), then green 0-100, the blue 0-100, getting new color on while
   old color is fading out.

*/

// Because I tend to forget - the number here is the Port B pin in use.  Pin 5 is PB0, Pin 6 is PB1, etc.
#define LINE_A 0 // PB0 / Pin 5 on ATtiny85 / Pin 14 on an ATmega328 (D8)
#define LINE_B 1 // PB1 / Pin 6 on ATtiny85 / Pin 15 on an ATmega328 (D9) 
#define LINE_C 2 // PB2 / Pin 7 on ATtiny85 / Pin 17 on an ATmega328 (D11)
#define LINE_D 3 // PB3 / Pin 2 on ATtiny85 / Pin 18 on an ATmega328 (D12)
#define LINE_E 4 // PB4 / Pin 3 on ATtiny85

#include <avr/sleep.h>
#include <avr/power.h>
#include <EEPROM.h>

// How many modes do we want to go through?
#define MAX_MODE 14
// How long should I draw each color on each LED?
#define DRAW_TIME 25

// Location of the brown-out disable switch in the MCU Control Register (MCUCR)
#define BODS 7 
// Location of the Brown-out disable switch enable bit in the MCU Control Register (MCUCR)
#define BODSE 2 

// The base unit for the time comparison. 1000=1s, 10000=10s, 60000=1m, etc.
//#define time_multiplier 1000 
#define time_multiplier 60000
// How many time_multiplier intervals should run before going to sleep?
#define run_time 240

#define MAX_HUE 360 // normalized

// How bit-crushed do you want the bit depth to be?  1 << DEPTH is how
// quickly it goes through the LED softpwm scale.

// 1 means 128 shades per color.  3 is 32 colors while 6 is 4 shades per color.
// it sort of scales the time drawing routine, but not well.

// It mostly affects how much POV flicker there is - 
// 1 is moderately flickery, but the color depth is the best.
// 3 is about the best balance of color depth and flicker

// The flicker is visible in all modes, the depth crushing starts to be evident
// in the SBWalk modes.  Mode 7 is the touchstone for not having enough bits.

// The build uses 1 for the PTH versions and 3 for the SMD displays.

#define DEPTH 3

byte __attribute__ ((section (".noinit"))) last_mode;

uint8_t led_grid[15] = {
  000 , 000 , 000 , 000 , 000 , // R
  000 , 000 , 000 , 000 , 000 , // G
  000 , 000 , 000 , 000 , 000  // B
};

uint8_t led_grid_next[15] = {
  000 , 000 , 000 , 000 , 000 , // R
  000 , 000 , 000 , 000 , 000 , // G
  000 , 000 , 000 , 000 , 000  // B
};


void setup() {
  if(bit_is_set(MCUSR, PORF)) { // Power was just established!
    MCUSR = 0; // clear MCUSR
    EEReadSettings(); // read the last mode out of eeprom
  } 
  else if(bit_is_set(MCUSR, EXTRF)) { // we're coming out of a reset condition.
    MCUSR = 0; // clear MCUSR
    last_mode++; // advance mode

    if(last_mode > MAX_MODE) {
      last_mode = 0; // reset mode
    }
  }

  // Try and set the random seed more randomly.  Alternate solutions involve
  // using the eeprom and writing the last seed there.
  uint16_t seed=0;
  uint8_t count=32;
  while (--count) {
    seed = (seed<<1) | (analogRead(1)&1);
  }
  randomSeed(seed);
}

void loop() {
  // indicate which mode we're entering
  led_grid[last_mode] = 255>>DEPTH;
  draw_for_time(1000);
  led_grid[last_mode] = 0;
  delay(250);

  // If EXTRF hasn't been asserted yet, save the mode
  EESaveSettings();

  // go into the modes
  switch(last_mode) {
    // red modes
  case 0: 
    HueWalk(run_time,millis(),20,1); // wide virtual space, slow progression
    break;
  case 1:
    HueWalk(run_time,millis(),20,2); // wide virtual space, medium progression
    break;
  case 2:
    HueWalk(run_time,millis(),20,5); // wide virtual space, fast progression
    break;
  case 3:
    HueWalk(run_time,millis(),5,1); // 1:1 space to LED, slow progression
    break;
  case 4:
    HueWalk(run_time,millis(),5,2); // 1:1 space to LED, fast progression
    break;
    // green modes
  case 5: 
    RandomColorRandomPosition(run_time,millis());
    break;
  case 6:
    RandHueWalk(run_time,millis()); // It's a lot like the prior mode, but with color shifting
    break;
  case 7:
    SBWalk(run_time,millis(),1,1); // Slow progression through hues modifying brightness
    break; 
  case 8:
    SBWalk(run_time,millis(),4,1); // fast progression through hues modifying brightness
    break;
  case 9:
    PrimaryColors(run_time,millis()); // just a bulb check, to be honest.
    break;
    // blue modes
  case 10:
    BiColorWalk(run_time, millis(), 0, 120); // red to green, works great
    break;
  case 11:
    BiColorWalk(run_time, millis(), 120, 240); // green to blue, works great
    break;
  case 12:
    BiColorWalk(run_time, millis(), 240, 359); // blue to red, works great - setting endhue to 0 makes it a very wiiiide walk.
    break;
  case 13:
    {
      uint16_t starthue = random(360);
      uint16_t endhue = starthue + 120;
      BiColorWalk(run_time, millis(), starthue, endhue);
      break;
    }
  case 14:
    AllRand();
    break;
  }
  SleepNow();
}

void AllRand(void) {
  uint8_t allrand_time = 5;
  // Clear the display so it doesn't have any cruft left over from the prior mode.
  while(1) {
    for(int x = 0; x<=15; x++) {
      led_grid[x] = 0;
    }
    
    int randmode = random(14); // the 15th mode would be itself.
    
    switch(randmode) {
      // red modes
    case 0: 
      HueWalk(allrand_time,millis(),20,1); // wide virtual space, slow progression
      break;
    case 1:
      HueWalk(allrand_time,millis(),20,2); // wide virtual space, medium progression
      break;
    case 2:
      HueWalk(allrand_time,millis(),20,5); // wide virtual space, fast progression
      break;
    case 3:
      HueWalk(allrand_time,millis(),5,1); // 1:1 space to LED, slow progression
      break;
    case 4:
      HueWalk(allrand_time,millis(),5,2); // 1:1 space to LED, fast progression
      break;
      // green modes
    case 5: 
      RandomColorRandomPosition(allrand_time,millis());
      break;
    case 6:
      SBWalk(allrand_time,millis(),1,1); // Slow progression through hues modifying brightness
      break; 
    case 7:
      SBWalk(allrand_time,millis(),4,1); // fast progression through hues modifying brightness
      break;
    case 8:
      PrimaryColors(allrand_time,millis());
      break;
    case 9:
      RandHueWalk(allrand_time,millis());
      break;
      // blue modes
    case 10:
      BiColorWalk(allrand_time, millis(), 0, 120); // red to green, works great
      break;
    case 11:
      BiColorWalk(allrand_time, millis(), 120, 240); // green to blue, works great
      break;
    case 12:
      BiColorWalk(allrand_time, millis(), 240, 359); // blue to red, works great - setting endhue to 0 makes it a very wiiiide walk.
      break;
    case 13:
      {
	uint16_t starthue = random(360);
	uint16_t endhue = starthue + 120;
	BiColorWalk(allrand_time, millis(), starthue, endhue);
	break;
      }
    }
  }
}
void SleepNow(void) {
  // decrement last_mode, so the EXTRF increment sets it back to where it was.
  // note: this actually doesn't work that great in cases where power is removed after the MCU goes to sleep.
  // On the other hand, that's an edge condition that I'm not going to worry about too much.
  last_mode--;

  // mode is type byte, so when it rolls below 0, it will become a Very
  // Large Number compared to MAX_MODE.  Set it to MAX_MODE and the setup
  // routine will jump it up and down by one.
  if(last_mode > MAX_MODE) { last_mode = MAX_MODE; }

  EESaveSettings();

  // Important power management stuff follows
  ADCSRA &= ~(1<<ADEN); // turn off the ADC
  ACSR |= _BV(ACD);     // disable the analog comparator
  MCUCR |= _BV(BODS) | _BV(BODSE); // turn off the brown-out detector

  set_sleep_mode(SLEEP_MODE_PWR_DOWN); // do a complete power down
  sleep_enable(); // enable sleep mode
  sei();  // allow interrupts to end sleep mode
  sleep_cpu(); // go to sleep
  delay(500);
  sleep_disable(); // disable sleep mode for safety
}

/* currently funky.

void LarsonScanner(uint16_t time, uint32_t start_time, bool sleep) {
  int8_t direction = 1;
  uint8_t active = 1;
  uint8_t width = 5;
  int array[width];
  int mode = 1;

  // blank out the array...
  for(uint8_t x = 0; x<width; x++) {
    array[x] = 0;
  }

  uint16_t hue = random(MAX_HUE);

  while(1) {
    if(millis() >= (start_time + (time * time_multiplier))) { 
      if(sleep) {
	SleepNow();
      }
      else {
	break;
      }
    }

    // change which member is the active member
    if(direction == 1) { active++; }
    else               { active--; }

    if(mode == 1) {
      if(active > (width-1)) {
	active = 0;
	hue++;
	if(hue >= MAX_HUE) 
	  hue = 0;
      }
    }
    // If the active element will go outside of the realm of the array
    else if ( mode == 0 ) {
      if((active >= (width - 1)) // high side match
	 || (active < 1 )) {  // low side match
	if(direction == 1)       { direction = -1; }
	else if(direction == -1) { direction = 1; }
      }
    }

    // pin the currently active member to the maximum brightness
    array[active] = 255;

    // dim the other members of the array

    // start 1 element off the current.  If I start at 0, I would be
    // dimming the currently active element.
    for(uint8_t x = 0; x<width; x++) {
      // constrain the edits to real array elements.
      if(x != active) {
	array[x] -= (255/(width)+25);
      }
      if(array[x] < 0) { array[x] = 0; }
    }

    uint8_t displaypos = 0;
    for(uint8_t x = 0; x < width; x++) {
      setLedColorHSV(displaypos, hue, 255, array[x]);
      displaypos++;
    }
    fade_to_next_frame();
  }
  return;
}
*/
  
void RandomColorRandomPosition(uint16_t time, uint32_t start_time) {
  // preload all the LEDs with a color
  for(int x = 0; x<5; x++) {
    setLedColorHSV(x, random(MAX_HUE), 255, 255);
  }
  // and start blinking new ones in once a second.
  while(1) {
    setLedColorHSV(random(5), random(MAX_HUE), 255, 255);
    draw_for_time(1000);
    if(millis() >= (start_time + (time * time_multiplier))) { break; }
  }
}

void HueWalk(uint16_t time, uint32_t start_time, uint8_t width, uint8_t speed) {
  while(1) {
    
    if(millis() >= (start_time + (time * time_multiplier))) { break; }

    for(int16_t colorshift=MAX_HUE; colorshift>0; colorshift = colorshift - speed) {

      if(millis() >= (start_time + (time * time_multiplier))) { break; }
      for(uint8_t led = 0; led<5; led++) {
	uint16_t hue = ((led) * MAX_HUE/(width)+colorshift)%MAX_HUE;
	setLedColorHSV(led, hue, 255, 255);
      }
      draw_for_time(DRAW_TIME);
    }
  }
}

/*
time: How long it should run
jump: How much should hue increment every time an LED flips direction?
mode: 
  1 = walk through brightnesses at full saturation, 
  2 = walk through saturations at full brightness.
1 tends towards colors & black, 2 tends towards colors & white.
note: mode 2 is kind of funny looking with the current HSV->RGB code.  
*/
void SBWalk(uint16_t time, uint32_t start_time, uint8_t jump, uint8_t mode) {
  uint8_t scale_max, delta;
  uint16_t hue = random(MAX_HUE); // initial color
  uint8_t led_val[5] = {37,29,21,13,5}; // some initial distances
  bool led_dir[5] = {1,1,1,1,1}; // everything is initially going towards higher brightnesses

  scale_max = 254; 
  delta = 2; 

  while(1) {
    if(millis() >= (start_time + (time * time_multiplier))) { break; }
    for(uint8_t led = 0; led<5; led++) {
      if(mode == 1) {
	setLedColorHSV(led, hue, 254,          led_val[led]);
      } 
      else if (mode == 2) {
	setLedColorHSV(led, hue, led_val[led], 254);
      }
      
      // if the current value for the current LED is about to exceed the top or the bottom, invert that LED's direction
      if((led_val[led] >= (scale_max-delta)) or (led_val[led] <= (0+delta))) {
	led_dir[led] = !led_dir[led];
	if(led_val[led] <= (0+delta)) {
	  hue += jump;
	}
	if(hue >= MAX_HUE)
	  hue = 0;
      }
      if(led_dir[led] == 1)
        led_val[led] += delta;
      else 
        led_val[led] -= delta;
    }
    draw_for_time(10);
  }
}

void PrimaryColors(uint16_t time, uint32_t start_time) {
  uint8_t led_bright = 1;
  bool led_dir = 1;
  uint8_t led = 0;
  while(1) {
    if(millis() >= start_time + (time*time_multiplier)) { break; }
    
    // flip the direction when the LED is at full brightness or no brightness.
    if((led_bright >= (255>>DEPTH)) or (led_bright <= 0))
      led_dir = !led_dir;
    
    // increment or decrement the brightness
    if(led_dir == 1)
      led_bright++;
    else
      led_bright--;
    
    // if the decrement will turn off the current LED, switch to the next LED
    if( led_bright <= 0 ) { 
      led_grid[led] = 0; 
      led++; 
    }
    
    // And if that change pushes the current LED off the end of the spire, reset to the first LED.
    if( led >=15) 
      led = 0; 

    // push the change out to the array.
    led_grid[led] = led_bright;
    draw_for_time(2*(DEPTH+1));
  }
}

// rotate 5 random color distances around the ring. Works quite nicely.  Leans heavily on randomseed being random.
void RandHueWalk(uint16_t time, uint32_t start_time) {
  uint16_t ledhue[] = {random(360), random(360), random(360), random(360), random(360)};
  while(1) {
    
    if(millis() >= (start_time + (time * time_multiplier))) { break; }
    
    for(uint8_t led = 0; led<5; led++) {
      
      uint16_t hue = ledhue[led]--;
      
      if(hue == 0) { ledhue[led] = 359; }
      setLedColorHSV(led, hue, 255, 255);
    }
    draw_for_time(DRAW_TIME); // this gets called 5 times, once per LED.
  }
}

/* Additional ideas:
1) Consider hitting endhue, then desaturating to white and ending up at the starthue.
2) Maybe put all 5 LEDs on slightly different hues within the same start/endhue progression, then larson the colors back and forth?
*/

void BiColorWalk(uint16_t time, uint32_t start_time, uint16_t starthue, uint16_t endhue) {
  uint16_t curhue = starthue;
  int8_t curdir = 1;
  while(1) {
    if(millis() >= (start_time + (time * time_multiplier))) { break; }

    curhue += curdir;
    if(curhue == endhue) { curdir = -1; }
    if(curhue == starthue) { curdir = 1; }

    for(uint8_t led = 0; led < 5; led++) {
      setLedColorHSV(led, curhue, 255, 255);
    }
    draw_for_time(DRAW_TIME * 3);
  }
}
  
const byte dim_curve[] = {
  0,   1,   1,   2,   2,   2,   2,   2,   2,   3,   3,   3,   3,   3,   3,   3,
  3,   3,   3,   3,   3,   3,   3,   4,   4,   4,   4,   4,   4,   4,   4,   4,
  4,   4,   4,   5,   5,   5,   5,   5,   5,   5,   5,   5,   5,   6,   6,   6,
  6,   6,   6,   6,   6,   7,   7,   7,   7,   7,   7,   7,   8,   8,   8,   8,
  8,   8,   9,   9,   9,   9,   9,   9,   10,  10,  10,  10,  10,  11,  11,  11,
  11,  11,  12,  12,  12,  12,  12,  13,  13,  13,  13,  14,  14,  14,  14,  15,
  15,  15,  16,  16,  16,  16,  17,  17,  17,  18,  18,  18,  19,  19,  19,  20,
  20,  20,  21,  21,  22,  22,  22,  23,  23,  24,  24,  25,  25,  25,  26,  26,
  27,  27,  28,  28,  29,  29,  30,  30,  31,  32,  32,  33,  33,  34,  35,  35,
  36,  36,  37,  38,  38,  39,  40,  40,  41,  42,  43,  43,  44,  45,  46,  47,
  48,  48,  49,  50,  51,  52,  53,  54,  55,  56,  57,  58,  59,  60,  61,  62,
  63,  64,  65,  66,  68,  69,  70,  71,  73,  74,  75,  76,  78,  79,  81,  82,
  83,  85,  86,  88,  90,  91,  93,  94,  96,  98,  99,  101, 103, 105, 107, 109,
  110, 112, 114, 116, 118, 121, 123, 125, 127, 129, 132, 134, 136, 139, 141, 144,
  146, 149, 151, 154, 157, 159, 162, 165, 168, 171, 174, 177, 180, 183, 186, 190,
  193, 196, 200, 203, 207, 211, 214, 218, 222, 226, 230, 234, 238, 242, 248, 255,
};


/*
Inputs:
  p : LED to set
  immediate : Whether the change should go to led_grid or led_grid_next
  hue : 0-359 - color
  sat : 0-255 - how saturated should it be? 0=white, 255=full color
  val : 0-255 - how bright should it be? 0=off, 255=full bright
*/
void setLedColorHSV(uint8_t p, int16_t hue, int16_t sat, int16_t val) {

  /*
    so dim_curve duplicates too many of the low numbers too long, causing the
    animations to look janky.  Maybe 6 2's and 14 3's can be adjusted in other ways.
    
    val = dim_curve[val];
    sat = 255-dim_curve[255-sat];
  */

  while (hue > 359) hue -= 360;
  while (hue < 0) hue += 361;

  int r, g, b, base;

  if (sat == 0) { // Acromatic color (gray). Hue doesn't mind.
    r = g = b = val;
  }
  else {
    base = ((255 - sat) * val)>>8;

    switch(hue/60) {
    case 0:
      r = val;
      g = (((val-base)*hue)/60)+base;
      b = base;
      break;

    case 1:
      r = (((val-base)*(60-(hue%60)))/60)+base;
      g = val;
      b = base;
      break;

    case 2:
      r = base;
      g = val;
      b = (((val-base)*(hue%60))/60)+base;
      break;

    case 3:
      r = base;
      g = (((val-base)*(60-(hue%60)))/60)+base;
      b = val;
      break;

    case 4:
      r = (((val-base)*(hue%60))/60)+base;
      g = base;
      b = val;
      break;

    case 5:
      r = val;
      g = base;
      b = (((val-base)*(60-(hue%60)))/60)+base;
      break;
    }
  }

  // output range is 0-255
  // Shifting it to the DEPTH bits right crushes it to 127, 64, 32, 16, 8 shades per color.
  r = r>>DEPTH;
  g = g>>DEPTH;
  b = b>>DEPTH;

  set_led_rgb(p,r,g,b);
}

/* Args:
   position - 0-4
   red value - 0-255
   green value - 0-255
   blue value - 0-255
*/
void set_led_rgb (uint8_t p, uint8_t r, uint8_t g, uint8_t b) {
  led_grid[p] = r;
  led_grid[p+5] = g;
  led_grid[p+10] = b;
}

// runs draw_frame a supplied number of times.
void draw_for_time(uint16_t time) {
  for(uint16_t f = 0; f<time * (1 << (DEPTH-1)); f++) { draw_frame(); }
}

// Anode | cathode
const uint8_t led_dir[15] = {
  ( 1<<LINE_B | 1<<LINE_A ), // 1 r
  ( 1<<LINE_A | 1<<LINE_E ), // 2 r
  ( 1<<LINE_E | 1<<LINE_D ), // 3 r
  ( 1<<LINE_D | 1<<LINE_C ), // 4 r
  ( 1<<LINE_C | 1<<LINE_B ), // 5 r

  ( 1<<LINE_B | 1<<LINE_C ), // 1 g
  ( 1<<LINE_A | 1<<LINE_B ), // 2 g
  ( 1<<LINE_E | 1<<LINE_A ), // 3 g
  ( 1<<LINE_D | 1<<LINE_E ), // 4 g
  ( 1<<LINE_C | 1<<LINE_D ), // 5 g

  ( 1<<LINE_B | 1<<LINE_D ), // 1 b
  ( 1<<LINE_A | 1<<LINE_C ), // 2 b
  ( 1<<LINE_E | 1<<LINE_B ), // 3 b
  ( 1<<LINE_D | 1<<LINE_A ), // 4 b
  ( 1<<LINE_C | 1<<LINE_E ), // 5 b
};

//PORTB output config for each LED (1 = High, 0 = Low)
const uint8_t led_out[15] = {
  ( 1<<LINE_B ), // 1
  ( 1<<LINE_A ), // 2
  ( 1<<LINE_E ), // 3
  ( 1<<LINE_D ), // 4
  ( 1<<LINE_C ), // 5
  
  ( 1<<LINE_B ), // 1
  ( 1<<LINE_A ), // 2
  ( 1<<LINE_E ), // 3
  ( 1<<LINE_D ), // 4
  ( 1<<LINE_C ), // 5
  
  ( 1<<LINE_B ), // 1
  ( 1<<LINE_A ), // 2
  ( 1<<LINE_E ), // 3
  ( 1<<LINE_D ), // 4
  ( 1<<LINE_C ), // 5
};

void light_led(uint8_t led_num) { //led_num must be from 0 to 19
  //DDRD is the ports in use on an ATmega328, DDRB on an ATtiny85
  DDRB = led_dir[led_num];
  PORTB = led_out[led_num];
}

void leds_off() {
  DDRB = 0;
  PORTB = 0;
}

void draw_frame(void){
  uint16_t b;
  uint8_t led;
  // giving the loop a bit of breathing room seems to prevent the last LED from flickering.  Probably optimizes into oblivion anyway.
  for ( led=0; led<15; led++ ) { 
    // software PWM 
    // input range is 0 (off) to 255>>DEPTH (127/63/31/etc) (fully on)

    // Light the LED in proportion to the value in the led_grid array
    for( b=0; b < led_grid[led]; b++ ) {
      light_led(led);
    }

    // and turn the LEDs off for the amount of time in the led_grid array
    // between LED brightness and 255>>DEPTH.
    for( b=led_grid[led]; b < 255>>DEPTH; b++ ) {
      leds_off();
    }
  }

  // Force the LEDs off - otherwise if the last LED on (led 14) was at full
  // brightness at the end of the softPWM, it would never actually get turned
  // off and would flicker. (mostly visible in the SB_Walk modes, if you want to
  // test it)
  leds_off();
}

void EEReadSettings (void) {  // TODO: Detect ANY bad values, not just 255.
  byte detectBad = 0;
  byte value = 255;
  
  value = EEPROM.read(0);
  if (value > MAX_MODE)
    detectBad = 1;
  else
    last_mode = value;  // MainBright has maximum possible value of 8.
  
  if (detectBad)
    last_mode = 0; // I prefer the rainbow effect.
}

void EESaveSettings (void){
  //EEPROM.write(Addr, Value);
  
  // Careful if you use  this function: EEPROM has a limited number of write
  // cycles in its life.  Good for human-operated buttons, bad for automation.
  
  byte value = EEPROM.read(0);

  if(value != last_mode)
    EEPROM.write(0, last_mode);
}

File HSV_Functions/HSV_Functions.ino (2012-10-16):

/*
Notes:

Execution time - They all take roughly the same amount of time to execute - none
                 are particularly faster over 255 runs (at millis scales anyway
                 - all ~230ms at 16mhz)

------------------------------------------------------------------------

Code size - with Serial enabled:

c1: 4366 bytes
c2: 2844 bytes
c3: 3252 (with dim_curve, which is ~200 bytes)
c4: 2848 bytes

------------------------------------------------------------------------

Accuracy - numerically at the 3 primary colors + 3 secondary colors (i.e. full
           bright on R/G/B and Y/C/M):

c1: highly accurate - all on and all off at 60 degree intervals
c2: Kind of sloppy, never actually hits 0 brightness.  However, it is mapping
    HSL space and not HSV space like the others.  Might be handy to have.
c3: Identical to the floating point version
c4: Curious quirk - the scale seems to be 0-135, then a gap to 248-255.  Almost
    invisible on actual LEDs due to how they scale, but it makes fading
    trickier.

------------------------------------------------------------------------

Test Output

-- C1: Floating point
255 0 0
255 255 0
0 255 0
0 255 255
0 0 255
255 0 255
-- C2: Integer #1
255 1 1
254 255 1
1 255 4
1 250 255
8 1 255
255 1 246
-- C3: Integer #2 (brightness curve applied)
255 0 0
255 255 0
0 255 0
0 255 255
0 0 255
255 0 255
-- C4: Integer #3 (current)
255 0 0
127 128 0
0 254 1
0 126 129
2 0 253
130 0 125


*/

void setup() {
  Serial.begin(115200);
}

void loop() {

  int x;

  Serial.println("-- C1: Floating point");
  for(x = 0; x<360; x=x+60) { // Range is 0 .. 360, incrementing hue by 60 results in RYGCBM points
    c1(x,255,255);
  }  
  
  Serial.println("-- C2: Integer #1");
  for(x = 0; x<255; x=x+43) { // range is 0 .. 255, incremending by 42/43 results in the RYGCBM points
    c2(x,255,128);
  }

  Serial.println("-- C3: Integer #2 (brightness curve applied)");
  for(x = 0; x<360; x=x+60) { // Range is 0 .. 360 again
    c3(x,255,255);
  }

  Serial.println("-- C4: Integer #3 (current)");
  for(x = 0; x<764; x=x+128) { // range is 0 .. 764, incrementing by 127/128 results in RYGCBM points.
    c4(x,128,255);
  }

  delay(500000);
}

/* inputs:
hue 0-764
sat 0-128
bri 0-255
*/


void c4(int16_t hue, int16_t sat, int16_t bri) {
  int16_t red_val, green_val, blue_val;

  while (hue > 764) hue -= 765;
  while (hue < 0) hue += 765;

  if (hue < 255) {
    red_val = (10880 - sat * (hue - 170)) >> 7;
    green_val = (10880 - sat * (85 - hue)) >> 7;
    blue_val = (10880 - sat * 85) >> 7;
  }
  else if (hue < 510) {
    red_val = (10880 - sat * 85) >> 7;
    green_val = (10880 - sat * (hue - 425)) >> 7;
    blue_val = (10880 - sat * (340 - hue)) >> 7;
  }
  else {
    red_val = (10880 - sat * (595 - hue)) >> 7;
    green_val = (10880 - sat * 85) >> 7;
    blue_val = (10880 - sat * (hue - 680)) >> 7;
  }

  int16_t r = (uint16_t)((bri + 1) * red_val) >> 8;
  int16_t g = (uint16_t)((bri + 1) * green_val) >> 8;
  int16_t b = (uint16_t)((bri + 1) * blue_val) >> 8;

  Serial.print(r); Serial.print(" ");
  Serial.print(g); Serial.print(" ");
  Serial.print(b); Serial.println();
}

const byte dim_curve[] = {
  0,   1,   1,   2,   2,   2,   2,   2,   2,   3,   3,   3,   3,   3,   3,   3,
  3,   3,   3,   3,   3,   3,   3,   4,   4,   4,   4,   4,   4,   4,   4,   4,
  4,   4,   4,   5,   5,   5,   5,   5,   5,   5,   5,   5,   5,   6,   6,   6,
  6,   6,   6,   6,   6,   7,   7,   7,   7,   7,   7,   7,   8,   8,   8,   8,
  8,   8,   9,   9,   9,   9,   9,   9,   10,  10,  10,  10,  10,  11,  11,  11,
  11,  11,  12,  12,  12,  12,  12,  13,  13,  13,  13,  14,  14,  14,  14,  15,
  15,  15,  16,  16,  16,  16,  17,  17,  17,  18,  18,  18,  19,  19,  19,  20,
  20,  20,  21,  21,  22,  22,  22,  23,  23,  24,  24,  25,  25,  25,  26,  26,
  27,  27,  28,  28,  29,  29,  30,  30,  31,  32,  32,  33,  33,  34,  35,  35,
  36,  36,  37,  38,  38,  39,  40,  40,  41,  42,  43,  43,  44,  45,  46,  47,
  48,  48,  49,  50,  51,  52,  53,  54,  55,  56,  57,  58,  59,  60,  61,  62,
  63,  64,  65,  66,  68,  69,  70,  71,  73,  74,  75,  76,  78,  79,  81,  82,
  83,  85,  86,  88,  90,  91,  93,  94,  96,  98,  99,  101, 103, 105, 107, 109,
  110, 112, 114, 116, 118, 121, 123, 125, 127, 129, 132, 134, 136, 139, 141, 144,
  146, 149, 151, 154, 157, 159, 162, 165, 168, 171, 174, 177, 180, 183, 186, 190,
  193, 196, 200, 203, 207, 211, 214, 218, 222, 226, 230, 234, 238, 242, 248, 255,
};

  /* convert hue, saturation and brightness ( HSB/HSV ) to RGB
     The dim_curve is used only on brightness/value and on saturation (inverted).
     This looks the most natural.      
  */

// from http://www.kasperkamperman.com/blog/arduino/arduino-programming-hsb-to-rgb/

// Uses up 3252 bytes of flash, about 200 of which is the dim curve.

void c3(int hue, int sat, int val) { 

  val = dim_curve[val];
  sat = 255-dim_curve[255-sat];

  int r, g, b, base;

  if (sat == 0) { // Acromatic color (gray). Hue doesn't mind.
    r = g = b = val;
  }
  else { 
    base = ((255 - sat) * val)>>8;
    
    switch(hue/60) {
    case 0:
      r = val;
      g = (((val-base)*hue)/60)+base;
      b = base;
      break;
      
    case 1:
      r = (((val-base)*(60-(hue%60)))/60)+base;
      g = val;
      b = base;
      break;
      
    case 2:
      r = base;
      g = val;
      b = (((val-base)*(hue%60))/60)+base;
      break;
      
    case 3:
      r = base;
      g = (((val-base)*(60-(hue%60)))/60)+base;
      b = val;
      break;
      
    case 4:
      r = (((val-base)*(hue%60))/60)+base;
      g = base;
      b = val;
      break;
      
    case 5:
      r = val;
      g = base;
      b = (((val-base)*(60-(hue%60)))/60)+base;
      break;
    }
  }   
  Serial.print(r); Serial.print(" ");
  Serial.print(g); Serial.print(" ");
  Serial.print(b); Serial.println();
}

/* hue: 0 ... 255
   sat: 0 ... 255
   lum: 0 ... 255
   
In practice: 
  As saturation drops from 255, colors become muted
  As luminance rises, colors brighten up, but eventually the color gets washed out in 255,255,255.  Max color saturation is at 128 (255,0,0 at hue 0)

This is the integer code, with the Serial lines it uses up 2844 bytes of flash.

Source: http://qscribble.blogspot.com/2008/06/integer-conversion-from-hsl-to-rgb.html (adapted)
*/
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

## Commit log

2012-09-25 Attempting to use MCUSR for power state management
2012-09-26 Well, that would explain why the 5th LED kept running out of sequence.
2012-09-26 Converted to integer code, regained about 17% of flash in the process.
    I think it looks a bit nicer, too - the brightness doesn't jump around
    so much.
    [TinyFiveCircle.ino]
2012-10-05 Tracking down an annoying failure to sleep inside LarsonScanner().
    Binary sketch size: 3,828 bytes (of a 8,192 byte maximum)
    [TinyFiveCircle.ino]
2012-10-08 Switched over to arduino-tiny core.
2012-10-10 Leading toward production board.
2012-10-16 Swapped to the more accurate HSV to RGB routine, made all the other required timing changes to account for the smaller hue space as well.
    [TinyFiveCircle.ino]
2012-10-16 Added fading function to larson scanner - looks nice.
    Binary sketch size: 3,918 bytes (of a 8,192 byte maximum)
    (The downside is I think I run up against perceptual issues at
    particular hues where 255 is significantly (redder/greener/bluer) than
    the trail is.)
    [TinyFiveCircle.ino]
2012-11-19 Revision 2 board
    Aside from some documentation changes (LED positions & etc), the major
    changes are the LED footprints, the addition of a reset pullup and a
    100nF cap on the power lines.
2012-11-19 Current revision hex files
2012-11-19 Updating fuses for 2.7v BOD instead of no BOD.
2012-11-19 Board management
2012-11-19 And turning off BOD again - it killed the sleep power consumption.
2013-01-16 Changing color depth from 8-bit (ish) to 6-bit.
    This improves PWM duty cycle (brighter!) and reduces that very edge of
    flicker it had been exhibiting with clear lensed LEDs like the surface
    mount kit uses.
2013-01-24 Eagle board and schematic snapshots
2013-01-26 Correcting a little unintentional misdirection in the comments
    1 was originally at the 12 o'clock position. Changing the order of the
    array changes where the "gap" is in several modes.
    [TinyFiveCircle.ino]
2013-01-26 A stub for testing new modes on a serial equipped board
2013-01-27 Bug fix in the hue correction - 360->0 sparkles, 359->0 doesn't.
    [TinyFiveCircle.ino]
2013-01-27 Bug fix in the hue correction & additional debugging flags
    [NewMode.ino]
2013-02-02 Implementing the new modes. It's getting a bit hard to keep track.
2013-02-12 Corrected a longstanding bug and cleaned up some slightly misleading code.
    [TinyFiveCircle.ino]
2013-12-08 Never committed the boards to the repository, whoops!
    [Tiny 5 Circle PTH -v3.brd, Tiny 5 Circle PTH -v3.sch, Tiny 5 Circle SMD -v3.brd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]

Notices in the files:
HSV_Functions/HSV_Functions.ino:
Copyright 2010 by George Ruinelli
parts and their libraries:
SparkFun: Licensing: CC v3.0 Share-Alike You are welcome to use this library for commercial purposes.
